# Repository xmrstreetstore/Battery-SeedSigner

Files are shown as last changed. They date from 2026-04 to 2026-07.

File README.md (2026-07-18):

<p align="center">
  SeedSigner logo
</p>

<h1 align="center">Battery SeedSigner</h1>
<p align="center"><b>Open-source hardware for <a href="https://seedsigner.com">SeedSigner</a></b> — an airgapped, camera-based Bitcoin signing device.</p>

<p align="center">
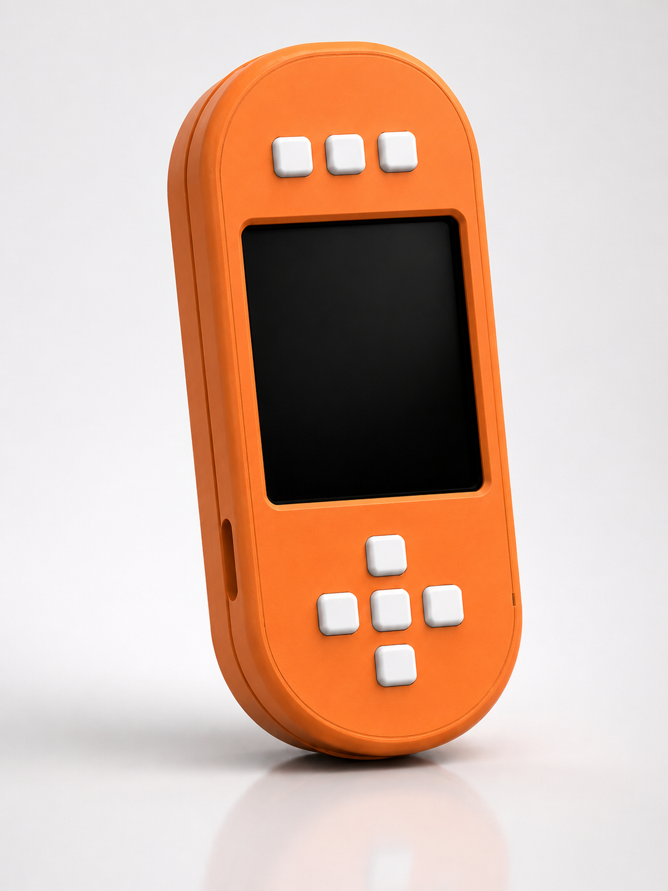
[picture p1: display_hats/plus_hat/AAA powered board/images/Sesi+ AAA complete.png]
Assembled battery-powered SeedSigner+
  
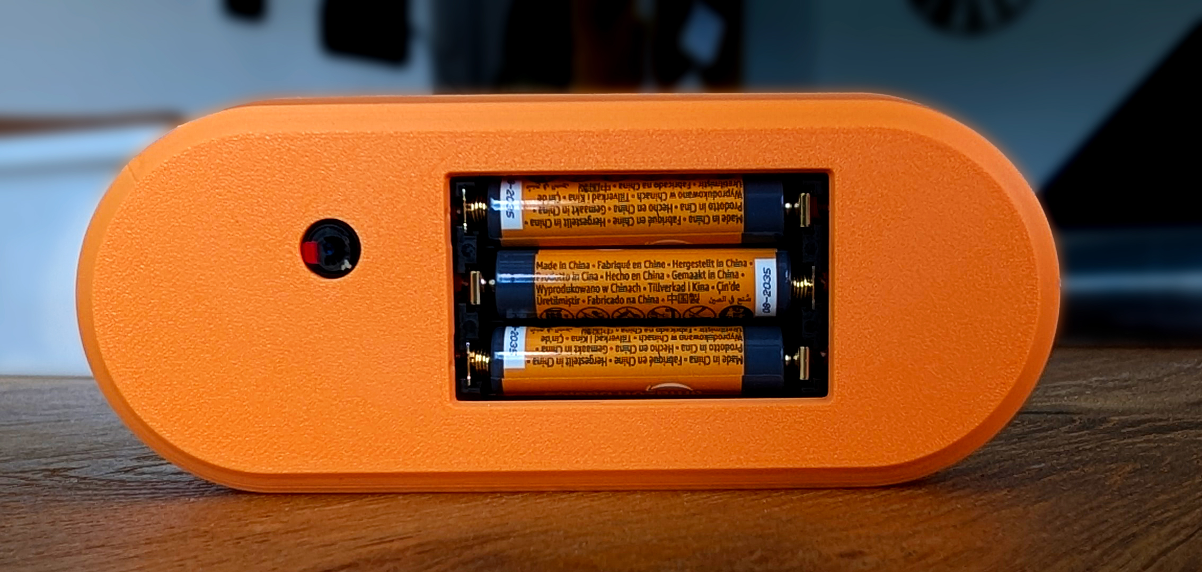
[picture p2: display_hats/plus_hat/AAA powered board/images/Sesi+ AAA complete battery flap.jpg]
Battery compartment with 3x AAA cells installed
  
</p>

This repository collects hardware designs for SeedSigner: display HATs, 3D-printable enclosures, and SeedQR paper templates. Its centerpiece is the **Battery SeedSigner** — a modified SeedSigner+ (SeSi+) board that runs entirely off 3x AAA batteries instead of USB power.

> **Runs stock SeedSigner OS.** This is a pure hardware/power mod — no custom firmware, OS build, or software changes of any kind. Flash the [official SeedSigner OS image](https://seedsigner.com) exactly as you would for any other SeedSigner build; the battery board just replaces the power source.

---

## What is the Battery SeedSigner?

The stock SeedSigner+ mainboard is powered over USB. This mod adds a small **3-pin connector** to the stock board (see the photos below) that mates via a short cable to a separate **3x AAA battery board**. The battery board holds three AAA cells and regulates their output to power the signer directly — no USB cable, no wall power, no computer required to use the device.

The result is a fully self-contained, battery-powered signer: drop in three AAA batteries, close the case, and sign transactions completely offline with nothing plugged in.

<p align="center">
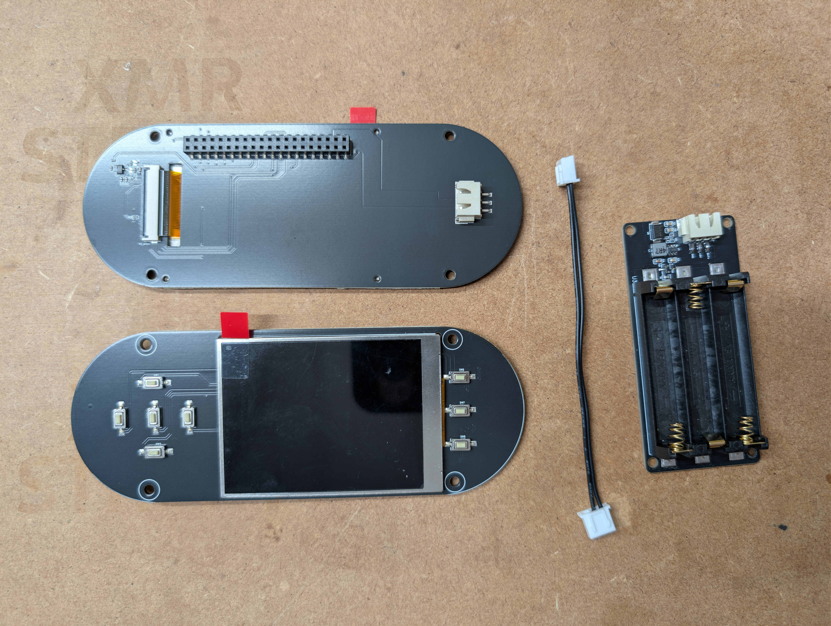
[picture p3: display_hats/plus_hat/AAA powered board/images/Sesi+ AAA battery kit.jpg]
Full kit: SeedSigner+ board, battery board, and connecting cable
  
</p>
<p align="center"><i>The kit: SeedSigner+ display/control board (top), 3x AAA battery board with connector cable (right).</i></p>

### Why

USB-powered airgapped signers still need to be plugged into *something* to receive power, which for many users means routing a cable to a phone charger, power bank, or computer — none of which is ideal for a device meant to stay fully isolated. Running the signer off primary AAA cells removes that dependency entirely: swap batteries and go, no charging infrastructure needed.

### How it works

| | |
|---|---|
| **Battery board** | Holds 3x AAA cells in series (~4.5V) and regulates the output to a stable 5V rail via an onboard converter. |
| **Connector** | A 3-pin cable links the battery board to a matching connector added to the stock SeSi+ board. Only 2 of the 3 pins are wired: **5V** and **GND**. The third pin is unused. |
| **Stock board mod** | The only change to the reference SeedSigner+ PCB is the added 3-pin connector — everything else, including the software it runs, matches the stock design. |

<p align="center">
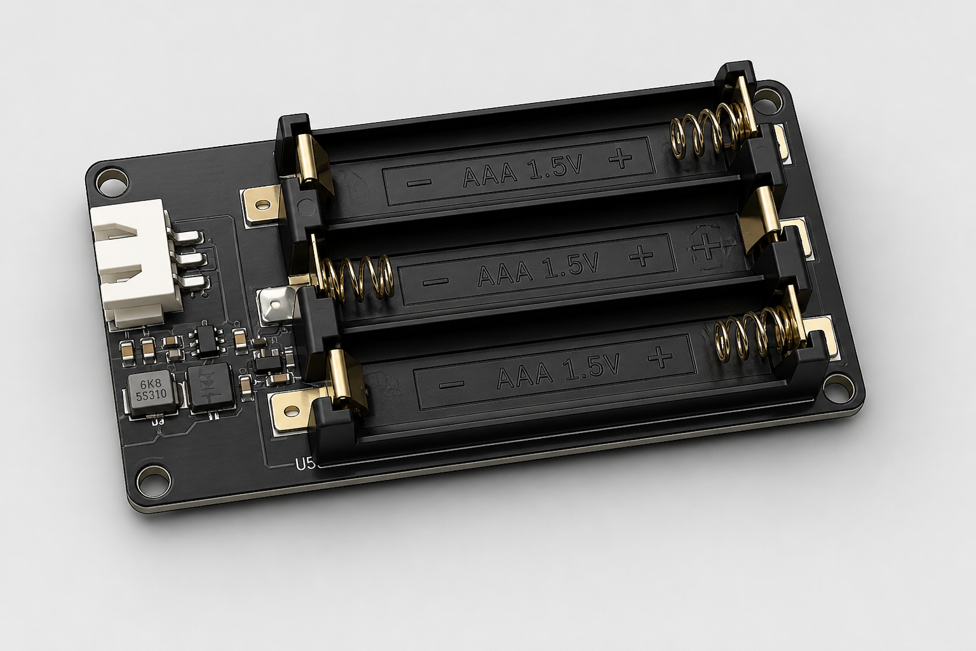
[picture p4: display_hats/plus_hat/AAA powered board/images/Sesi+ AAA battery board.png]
3x AAA battery board close-up
  
</p>
<p align="center"><i>The battery board: 3x AAA holder, regulator, and JST output connector.</i></p>

### Where to find the files

All design files, production files (BOM, pick-and-place, Gerbers), schematics, and 3D models for the battery board and the modified SeSi+ board live in:

```
display_hats/plus_hat/AAA powered board/
```

See that folder's [README](<display_hats/plus_hat/AAA powered board/README.md>) for the full file listing and BOM.

---

## Repository layout

| Folder | Contents |
|---|---|
| [`display_hats/plus_hat/`](display_hats/plus_hat) | The SeedSigner+ (SeSi+) display/control board, including the [Battery SeedSigner](<display_hats/plus_hat/AAA powered board>) mod above and the reference 2.8" LCD hat Gerbers. |
| [`signer_enclosures/`](signer_enclosures) | 3D-printable enclosures for various SeedSigner builds (Orange Pill, Open Pill, Rugged Pill, Push Case, SeedSigner+ reference design, and more). |
| [`seedqr_templates/`](seedqr_templates) | Printable PDF templates for recording SeedQR-encoded mnemonics on paper/cards. |
| [`img/`](img) | Shared product photos and the SeedSigner logo used across this README and sub-READMEs. |

Each enclosure/board subfolder has its own README with assembly notes, characteristics, and required hardware.

## License

Hardware designs in this repository are licensed under the [CERN Open Hardware Licence Version 2 - Strongly Reciprocal](LICENSE). SeedSigner itself is free, open-source software — see [seedsigner.com](https://seedsigner.com) and the [SeedSigner GitHub org](https://github.com/SeedSigner) for the signing device firmware and reference hardware this project builds on.

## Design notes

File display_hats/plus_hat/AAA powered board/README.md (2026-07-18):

# AAA Powered Board (Battery SeedSigner)

<p align="center">
  Assembled battery-powered SeedSigner+
</p>

A 3x AAA battery board for the SeedSigner+ (SeSi+) display/control board, letting it run untethered from USB power. The stock SeSi+ board is modified with a **3-pin connector** that mates to a matching connector on the battery board via a short cable — power flows straight from the batteries to the board, no USB or wall power involved.

This is a pure hardware power mod: the board runs the **official, unmodified SeedSigner OS**. No custom firmware, OS build, or software changes are needed — flash the standard SeedSigner image as usual.

## Characteristics

- Powers a SeedSigner+ board entirely from 3x AAA cells (~4.5V nominal)
- Onboard regulator delivers a stable 5V rail to the mainboard
- Connects to the SeSi+ board with a 3-pin cable — only **5V** and **GND** are wired; the third pin is unused
- Runs the stock, official SeedSigner OS — no firmware/software modification required

## Gallery

<p float="left">
	
	
</p>
<p float="left">
	
</p>

## Files

### Design sources

| File | Description |
|---|---|
| `AAA-Battery-board-EasyEDA-project.json` | EasyEDA Pro project file for the battery board |
| `AAA-Battery-board-SCH.json` | Battery board schematic (EasyEDA) |
| `AAA-Battery-board-Schematic.pdf` | Battery board schematic, PDF export |
| `AAA-Battery-board-3D file.step` | Battery board 3D model (STEP) |
| `AAA-SeSi+-EasyEDA-project.json` | EasyEDA Pro project file for the modified SeSi+ board |
| `AAA-SeSi+-SCH.json` | Modified SeSi+ board schematic (EasyEDA) |
| `AAA-SeSi+-3D file.step` | Modified SeSi+ board 3D model (STEP) |

### Production files (`Production files/`)

| File | Description |
|---|---|
| `BOM/AAA-Battery-board-BOM.csv` | Bill of materials — battery board |
| `BOM/AAA-Battery-board-PickAndPlace.csv` | Pick-and-place data — battery board |
| `BOM/AAA-SeSi+-BOM.csv` | Bill of materials — modified SeSi+ board |
| `BOM/AAA-SeSi+-PickAndPlace.csv` | Pick-and-place data — modified SeSi+ board |
| `Gerbers/AAA-Battery-board.zip` | Fabrication Gerbers — battery board |
| `Gerbers/AAA-SeSi+-gerbers.zip` | Fabrication Gerbers — modified SeSi+ board |

## Assembly

1. Fabricate or source both boards (see production files above).
2. Load 3x AAA cells into the battery board.
3. Connect the battery board to the modified SeSi+ board via the 3-pin cable.
4. Fit into a compatible enclosure with battery access (see [`signer_enclosures/`](../../../signer_enclosures)) — the flap-style cutout shown above allows swapping cells without disassembling the case.

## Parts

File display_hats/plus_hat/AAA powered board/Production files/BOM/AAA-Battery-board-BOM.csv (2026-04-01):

ID | Name | Designator | Footprint | Quantity | Manufacturer Part | Manufacturer | Supplier | Supplier Part | Price
1 | 22uF | C1,C2,C3 | C0603 | 3 | CL10A226MO7JZNC | SAMSUNG(三星) | LCSC | C2762594 | 0.045
2 | 10uF | C4 | C0603 | 1 | GRM188R61E106KA73D | muRata(村田) | LCSC | C344022 | 0.031
3 | ZX-XH2.54-3PWT | CN1 | CONN-SMD_3P-P2.54-XH2.54-WT | 1 | ZX-XH2.54-3PWT | Megastar(兆星) | LCSC | C7429672 | 0.059
4 | EDZVT2R12B | D1 | SOD-523_L1.2-W0.8-LS1.6-RD | 1 | EDZVT2R12B | ROHM(罗姆) | LCSC | C209629 | 0.03
5 | 4.7uH | L1 | IND-SMD_L4.1-W4.1_FTC404020S | 1 | FTC404020S4R7MGCA | cjiang(长江微电) | LCSC | C39676072 | 0.233
6 | SI2333CDS-T1-GE3 | Q1 | SOT-23_L2.9-W1.3-P1.90-LS2.4-BR | 1 | SI2333CDS-T1-GE3 | VISHAY(威世) | LCSC | C48179 | 0.212
7 | 100kΩ | R1 | R0603 | 1 | ARG03FTC1003 | Viking(光颉) | LCSC | C217682 | 0.008
8 | 110kΩ | R2 | R0402 | 1 | ARG02BTC1103 | Viking(光颉) | LCSC | C2984408 | 0.021
9 | MT3608L | U1 | SOT-23-6_L2.9-W1.6-P0.95-LS2.8-BL_3 | 1 | MT3608L | 西安航天民芯 | LCSC | C2932326 | 0.045
10 | 14.7kΩ | U2 | R0603 | 1 | RT0603BRD0714K7L | YAGEO(国巨) | LCSC | C705725 | 0.026
11 | SS510-SMB | U8 | SMB_L4.3-W3.6-LS5.3-RD | 1 | SS510-SMB | GOODWORK(固得沃克) | LCSC | C908687 | 0.047
12 | BH-AAA-B5AA005 | U3 | BAT-SMD_BH-AAA-B5AA005 | 1 | BH-AAA-B5AA005 | MYOUNG(美阳) | LCSC | C2979170 | 1.559

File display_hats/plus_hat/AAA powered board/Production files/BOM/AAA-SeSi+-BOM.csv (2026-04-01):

ID | Name | Designator | Footprint | Quantity | Manufacturer Part | Manufacturer | Supplier | Supplier Part | Price
1 | 100nF | C10 | C0402 | 1 | 04025C104KAT2A | Kyocera AVX | LCSC | C2167244 | 0.008
2 | ZX-XH2.54-3PWT | CN1 | CONN-SMD_3P-P2.54-XH2.54-WT | 1 | ZX-XH2.54-3PWT | Megastar(兆星) | LCSC | C7429672 | 0.063
3 | FPC-05FB-40PH20 | FPC2 | FPC-SMD_40P-P0.50_XUNPU_FPC-05FB-40PH20 | 1 | FPC-05FB-40PH20 | XUNPU(讯普) | LCSC | C2856837 | 0.231
4 | FH-00339 | H1 | HDR-SMD_40P-P2.54-V-F-R2-C20-S6.6_FH-00339 | 1 | FH-00339 | Liansheng(连盛) | LCSC | C2685112 | 0.581
5 | AO3416_C475604 | Q6 | SC-59-3_L2.9-W1.6-P0.95-LS2.9-BR | 1 | SK3416 | SHIKUES(时科) | LCSC | C475604 | 0.074
6 | 0Ω | R15,R17 | R0402 | 2 | 0402WGF0000TCE | UNI-ROYAL(厚声) | LCSC | C17168 | 0.001
7 | 47Ω | R18,R19,R20 | R0402 | 3 | 0402WGJ0470TCE | UNI-ROYAL(厚声) | LCSC | C25168 | 0.001
8 | 10kΩ | R21 | R0402 | 1 | 0402WGD1002TCE | UNI-ROYAL(厚声) | LCSC | C407753 | 0.002
9 | 33kΩ | R22 | R0402 | 1 | 0402WGF3302TCE | UNI-ROYAL(厚声) | LCSC | C25779 | 0.001
10 | 330Ω | R23 | R0402 | 1 | 0402WGD3300TCE | UNI-ROYAL(厚声) | LCSC | C423288 | 0.002
11 | TS-1101-C-W | SW1,SW2,SW3,SW4,SW5,SW6,SW7,SW8 | SW-SMD_L6.0-W3.3-LS8.0 | 8 | TS-1101-C-W | XKB Connectivity(中国星坤) | LCSC | C318938 | 0.043

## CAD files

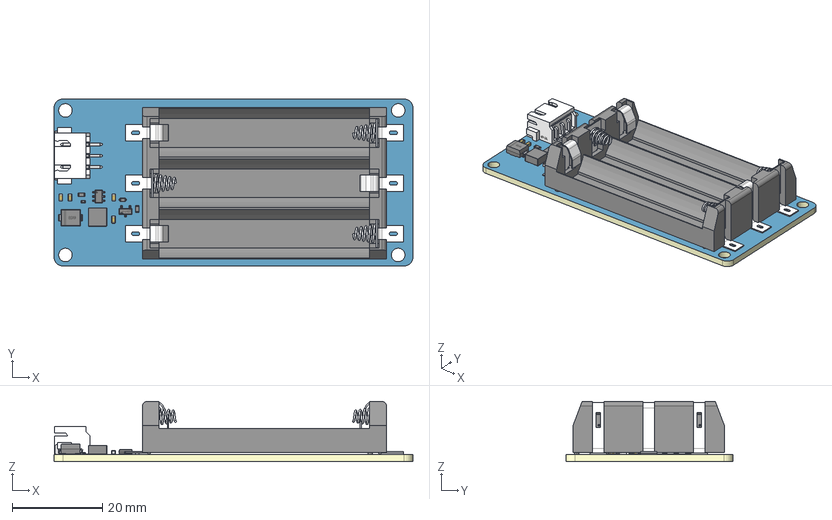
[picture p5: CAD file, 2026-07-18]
display_hats/plus_hat/AAA powered board/AAA-Battery-board-3D file.step
79.5 x 37.0 x 13.3 mm
Board~p7Y9
TopCopper~p7Y9
BottomCopper~p7Y9
TopFpcStiffener~p7Y9
BottomFpcStiffener~p7Y9
C0603~C0603_L1.6-W0.8-H0.8~p7Y9 x 4
SOT-23_L2.9-W1.3-P1.90-LS2.4-BR~SOT-23-3P_ L2.9-W1.3-H1.0-LS2.4-P0.95~p7Y9
R0603~R0603~p7Y9 x 2
R0402~R0402_L1.0-W0.5-H0.4~p7Y9
SOT-23-6_L2.9-W1.6-P0.95-LS2.8-BL_3~SOT-23-6_L2.9-W1.6-P0.95-LS2.8-BL_ 3~p7Y9
IND-SMD_L4.1-W4.1_FTC404020S~IND-SMD_L4.1-W4.1_FTC404020S~p7Y9
SMB_L4.3-W3.6-LS5.3-RD~SMB_L4.32-W3.62-LS5.3-RD~p7Y9
SOD-523_L1.2-W0.8-LS1.6-RD~SOD-523_L1.2-W0.8-H0.7-LS1.6~p7Y9
BAT-SMD_BH-AAA-B5AA005~BAT-SMD_BH-AAA-B5AA005~p7Y9
CONN-SMD_3P-P2.54-XH2.54-WT~CONN-SMD_3P-P2.54-XH2.54-WT~p7Y9

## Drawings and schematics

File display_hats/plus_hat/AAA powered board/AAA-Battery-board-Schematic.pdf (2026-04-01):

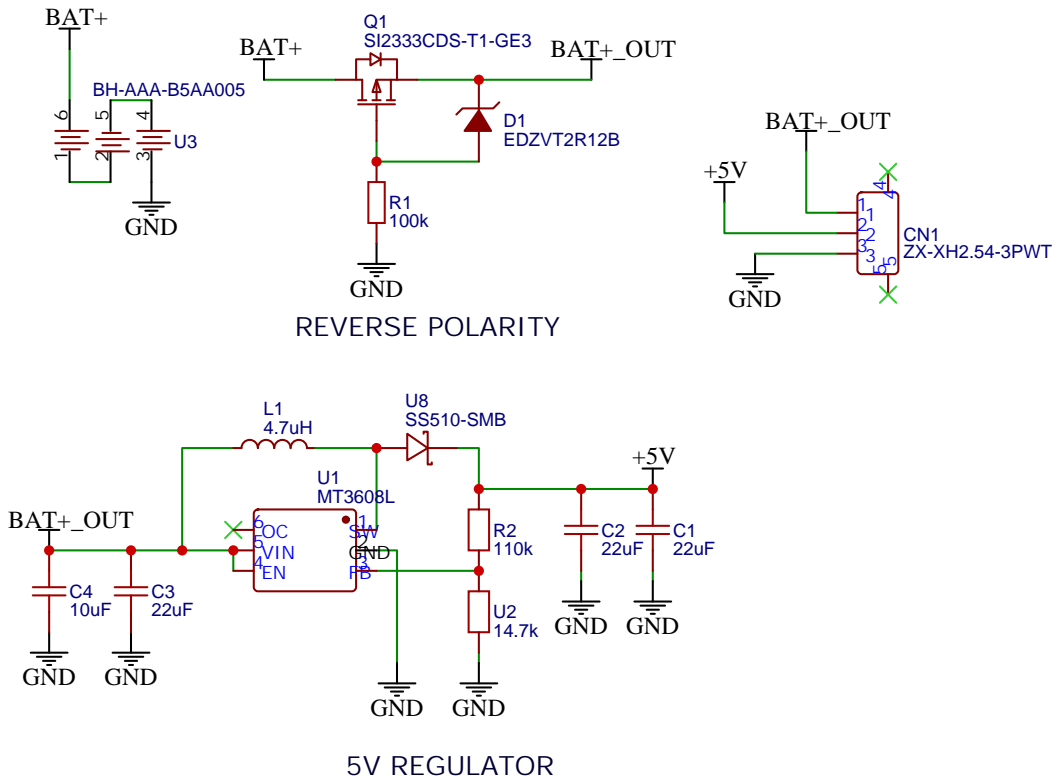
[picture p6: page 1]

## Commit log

2026-04-01 Add files via upload
    Uploaded gerber files
2026-04-01 Add files via upload
    Uploaded BOM and Pick and Place files
    [AAA-SeSi+-BOM.csv, AAA-SeSi+-PickAndPlace.csv]
2026-07-18 Restore AAA powered board files with updated EasyEDA sources
    Re-adds the battery board and SeSi+ stock board production files that
    were previously deleted, including the EasyEDA project/schematic JSON
    sources that weren't in the original commit.
    [AAA-Battery-board-3D file.step, AAA-Battery-board-BOM.csv, AAA-Battery-board-PickAndPlace.csv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]
2026-07-18 Add AAA powered board product photos and SeSi+ PCB 3D model
    Adds product/assembly photos (complete unit, battery board, battery
    compartment flap, full kit flat-lay) and the SeSi+ PCB STEP file,
    which previously only had gerbers/BOM with no 3D model.
2026-07-18 Write project front page and AAA powered board README
    Explains the Battery SeedSigner mod: a stock SeedSigner+ board with an
    added 3-pin connector that mates to a 3x AAA battery board, letting the
    signer run untethered from USB power. Adds a repo layout overview and
    a dedicated README documenting all files in the AAA powered board folder.
2026-07-18 Correct connector wiring and clarify stock OS in docs
    Only 5V and GND are wired on the 3-pin connector; the third pin is
    unused. Also clarifies this is a pure power mod running the official,
    unmodified SeedSigner OS with no firmware/software changes.
2026-07-18 Add battery board photos to shared img folder
    Copies the AAA powered board product photos into img/ alongside the
    existing enclosure photos. Existing img/ files are left untouched since
    several enclosure READMEs (open_pill, orange_pill, rugged_pill, etc.)
    still reference them.
